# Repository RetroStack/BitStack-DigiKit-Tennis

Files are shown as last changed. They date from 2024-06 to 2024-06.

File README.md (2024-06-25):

# DigiKit Tennis Replica

While watching my regular YouTube channels, I saw a digital electronics kit from the 70s called Tennis from the company DigiKit, [shown on the Tech Time Traveller](https://www.youtube.com/watch?v=UqEwdttDtZE&t=2260s). This is a neat little board with a fun game that looks useful for beginners to learn digital electronics. The provided schematic had a lot of bugs and was very incorrect. 

I spent some time reverse engineering it from screenshots of the YouTube video, and the result is this board.

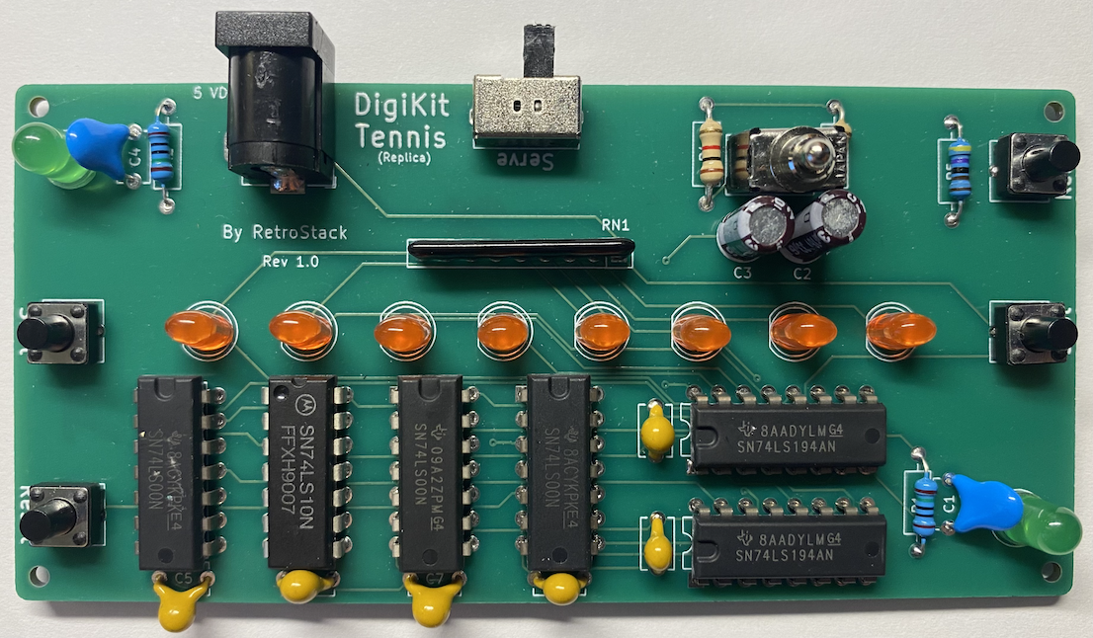
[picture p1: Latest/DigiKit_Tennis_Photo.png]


## Latest Files

In the "Latest" folder, you'll find the most up-to-date design files, including:

- Gerber files suitable for popular online PCB manufacturers like [PCBWay](/Latest/DigiKit_Tennis_Gerber_PCBWay.zip) and [JLCPCB](/Latest/DigiKit_Tennis_Gerber_JLCPCB.zip). Most manufacturers should be fine with either.
- A Bill of Materials (BOM) in both [CSV](/Latest/DigiKit_Tennis_BOM.csv) and [PDF](/Latest/DigiKit_Tennis_BOM.pdf) formats.
- The [full schematics](/Latest/DigiKit_Tennis_Schematics.pdf) of the board.

## How to Play

This is a simple game of Pong where the lights in the center of the board are used to indicate the path of the "ball." The goal of the game is to hit the ball back to the other player. When the player on the receiving end misses the ball, a point is given to the one sending it. The counting needs to be done independently and is not done on the board.

### How to set it up?

1. The first option to set is the toggle switch, which defines the speed of the ball. It should remain the same for the duration of the game.
2. Next, select who should serve the first ball. Switch the "Serve" slide switch to the side of the player who should serve. Then, press any "Reset" button. If the green light is not on the correct side of the person serving, switch it by pressing the "Shot" button from the other side. This will toggle the light.

### Play

When everything is set up, the serving player should press the "Shot" button on their side. (A red light and a green light should be lit on the same side!) As soon as "Shot" is pressed, a simulated "ball" is animated across the lights in the center. When the last light is reached, the other player needs to return it by pressing "Shot" in time on their side.

## Implementation

The replica has been implemented using KiCAD 8. The KiCAD project files are included in this repository.

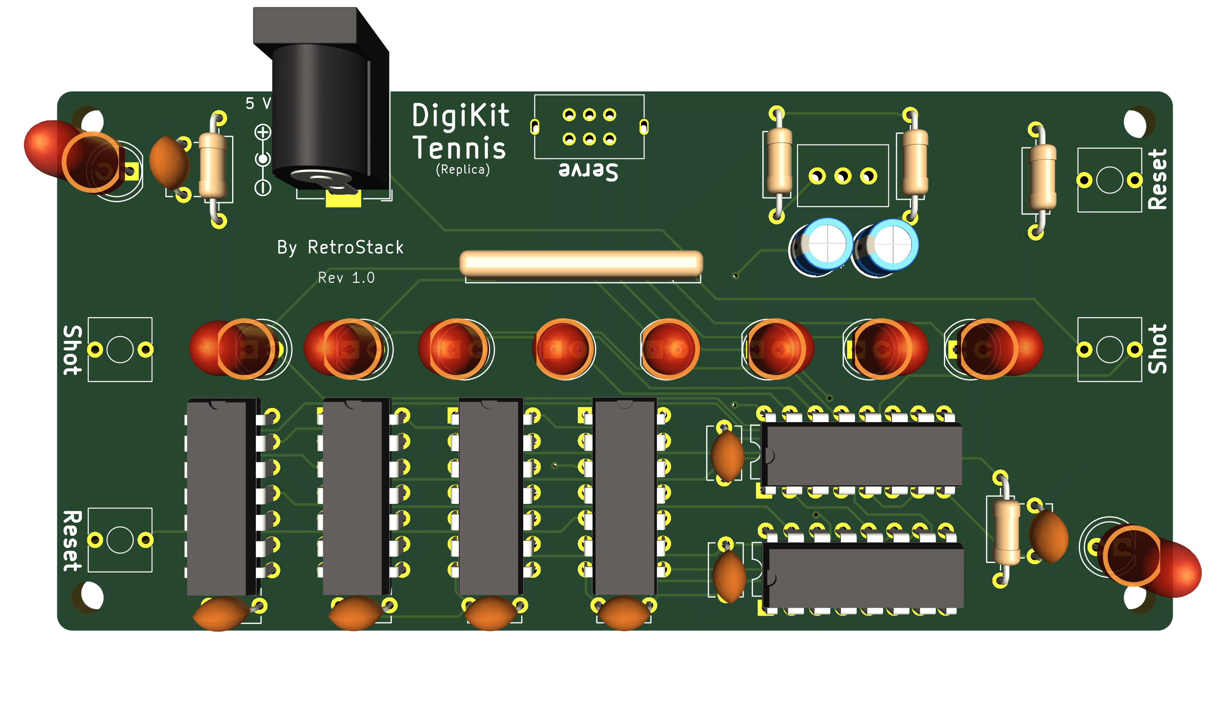
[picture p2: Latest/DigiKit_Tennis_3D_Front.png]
Replica Front

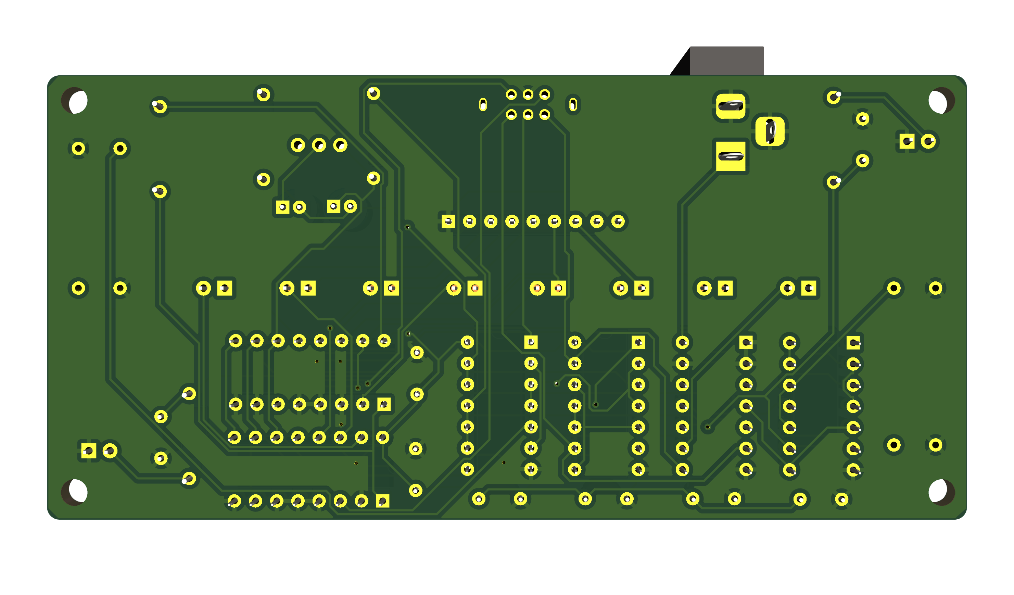
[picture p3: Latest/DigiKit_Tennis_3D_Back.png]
Replica Back


## Bill of Materials (BOM)

Below is a list of materials needed to assemble the PCB.

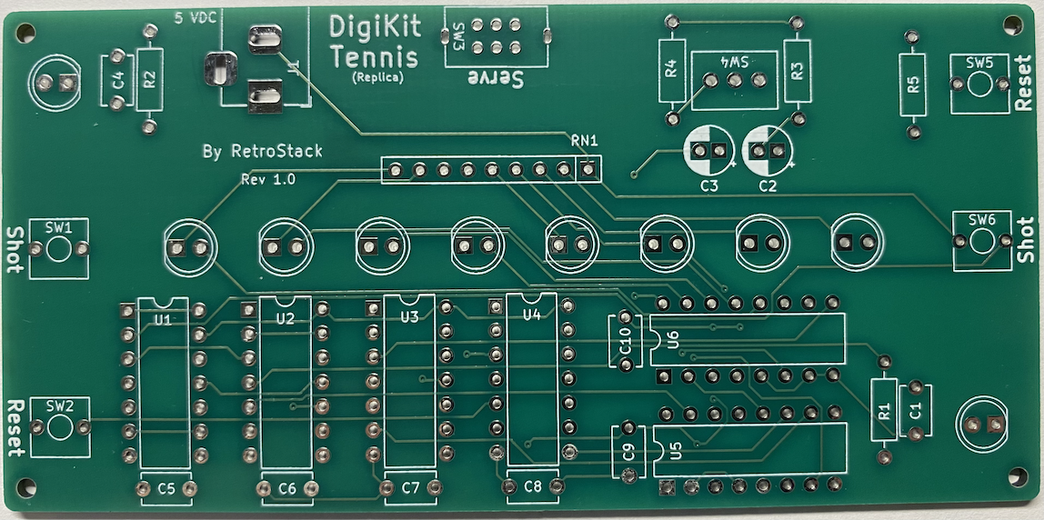
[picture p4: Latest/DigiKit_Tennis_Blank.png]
Board


| Reference | Qty | Description | Footprint | Datasheet |
| --- | --- | --- | --- | --- |
| C1,C4 | 2 | 2nF | Capacitor_THT:C_Disc_D5.1mm_W3.2mm_P5.00mm | |
| C2,C3 | 2 | 33uF | Capacitor_THT:CP_Radial_D5.0mm_P2.00mm | |
| C5,C6,C7,C8,C9,C10 | 6 | 0.1uF | Capacitor_THT:C_Disc_D5.1mm_W3.2mm_P5.00mm | |
| D1,D10 | 2 | Green | LED_THT:LED_D5.0mm | |
| D2,D3,D4,D5,D6,D7,D8,D9 | 8 | Red | LED_THT:LED_D5.0mm | |
| J1 | 1 | Barrel_Jack_Switch | Connector_BarrelJack:BarrelJack_Horizontal | |
| R1,R2,RN1 | 2 | 150 | Resistor_THT:R_Axial_DIN0207_L6.3mm_D2.5mm_P10.16mm_Horizontal | |
| RN1 | 1 | 150 | 8 Resistors; 9 pins | |
| R3,R4 | 2 | 1k | Resistor_THT:R_Axial_DIN0207_L6.3mm_D2.5mm_P10.16mm_Horizontal | |
| R5 | 1 | 4.7k | Resistor_THT:R_Axial_DIN0207_L6.3mm_D2.5mm_P10.16mm_Horizontal | |
| SW1 | 1 | Player A | RetroStackLibrary:SW_SPST_Push | |
| SW2 | 1 | Reset A | RetroStackLibrary:SW_SPST_Push | |
| SW3 | 1 | Serve | RetroStackLibrary:SW_DPDT_Slide_RightAngle | |
| SW4 | 1 | Speed | RetroStackLibrary:SW_SPDT_Toggle | |
| SW5 | 1 | Reset B | RetroStackLibrary:SW_SPST_Push | |
| SW6 | 1 | Player B | RetroStackLibrary:SW_SPST_Push | |
| U1,U3,U4 | 3 | 74LS00 | Package_DIP:DIP-14_W7.62mm | http://www.ti.com/lit/gpn/sn74ls00  |
| U2 | 1 | 74LS10 | Package_DIP:DIP-14_W7.62mm | http://www.ti.com/lit/gpn/sn74LS10  |
| U5,U6 | 2 | 74LS194 | Package_DIP:DIP-16_W7.62mm | http://www.ti.com/lit/gpn/sn74LS194 |

## RetroStack Libraries

To work with this KiCAD project, you'll need the RetroStack libraries for KiCAD. Please [follow this link](https://www.github.com/RetroStack/KiCAD-Libraries) to access and install these libraries.

## Support this Project

RetroStack is passionate about exploring and preserving the legacy of older computer systems. BitStack is a sub-project of RetroStack, focusing on education in digital electronics. My work involves creating detailed documentation and videos to share the knowledge. I am also dedicated to reviving these classic systems by reimplementing them and offering replacement parts at no cost. If you're keen on supporting this unique project, I invite you to visit my [Patreon page](https://www.patreon.com/RetroStack). Your support would be immensely valuable and greatly appreciated!

## License

This project is licensed under the MIT License - see the [LICENSE](LICENSE) file for details.

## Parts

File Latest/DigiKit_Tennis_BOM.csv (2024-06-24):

Reference | Value | Datasheet | Footprint | Qty
C1,C4 | 2nF | ~ | Capacitor_THT:C_Disc_D5.1mm_W3.2mm_P5.00mm | 2
C2,C3 | 33uF | ~ | Capacitor_THT:CP_Radial_D5.0mm_P2.00mm | 2
C5,C6,C7,C8,C9,C10 | 0.1uF | ~ | Capacitor_THT:C_Disc_D5.1mm_W3.2mm_P5.00mm | 6
D1,D10 | Green | ~ | LED_THT:LED_D5.0mm | 2
D2,D3,D4,D5,D6,D7,D8,D9 | Red | ~ | LED_THT:LED_D5.0mm | 8
J1 | Barrel_Jack_Switch | ~ | Connector_BarrelJack:BarrelJack_Horizontal | 1
R1,R2 | 150 | ~ | Resistor_THT:R_Axial_DIN0207_L6.3mm_D2.5mm_P10.16mm_Horizontal | 2
RN1 | 150 | ~ | 8 Resistors; 9 pin | 1
R3,R4 | 1k | ~ | Resistor_THT:R_Axial_DIN0207_L6.3mm_D2.5mm_P10.16mm_Horizontal | 2
R5 | 4.7k | ~ | Resistor_THT:R_Axial_DIN0207_L6.3mm_D2.5mm_P10.16mm_Horizontal | 1
SW1 | Player A | ~ | RetroStackLibrary:SW_SPST_Push | 1
SW2 | Reset A | ~ | RetroStackLibrary:SW_SPST_Push | 1
SW3 | Serve | ~ | RetroStackLibrary:SW_DPDT_Slide_RightAngle | 1
SW4 | Speed | ~ | RetroStackLibrary:SW_SPDT_Toggle | 1
SW5 | Reset B | ~ | RetroStackLibrary:SW_SPST_Push | 1
SW6 | Player B | ~ | RetroStackLibrary:SW_SPST_Push | 1
U1,U3,U4 | 74LS00 | http://www.ti.com/lit/gpn/sn74ls00 | Package_DIP:DIP-14_W7.62mm | 3
U2 | 74LS10 | http://www.ti.com/lit/gpn/sn74LS10 | Package_DIP:DIP-14_W7.62mm | 1
U5,U6 | 74LS194 | http://www.ti.com/lit/gpn/sn74LS194 | Package_DIP:DIP-16_W7.62mm | 2

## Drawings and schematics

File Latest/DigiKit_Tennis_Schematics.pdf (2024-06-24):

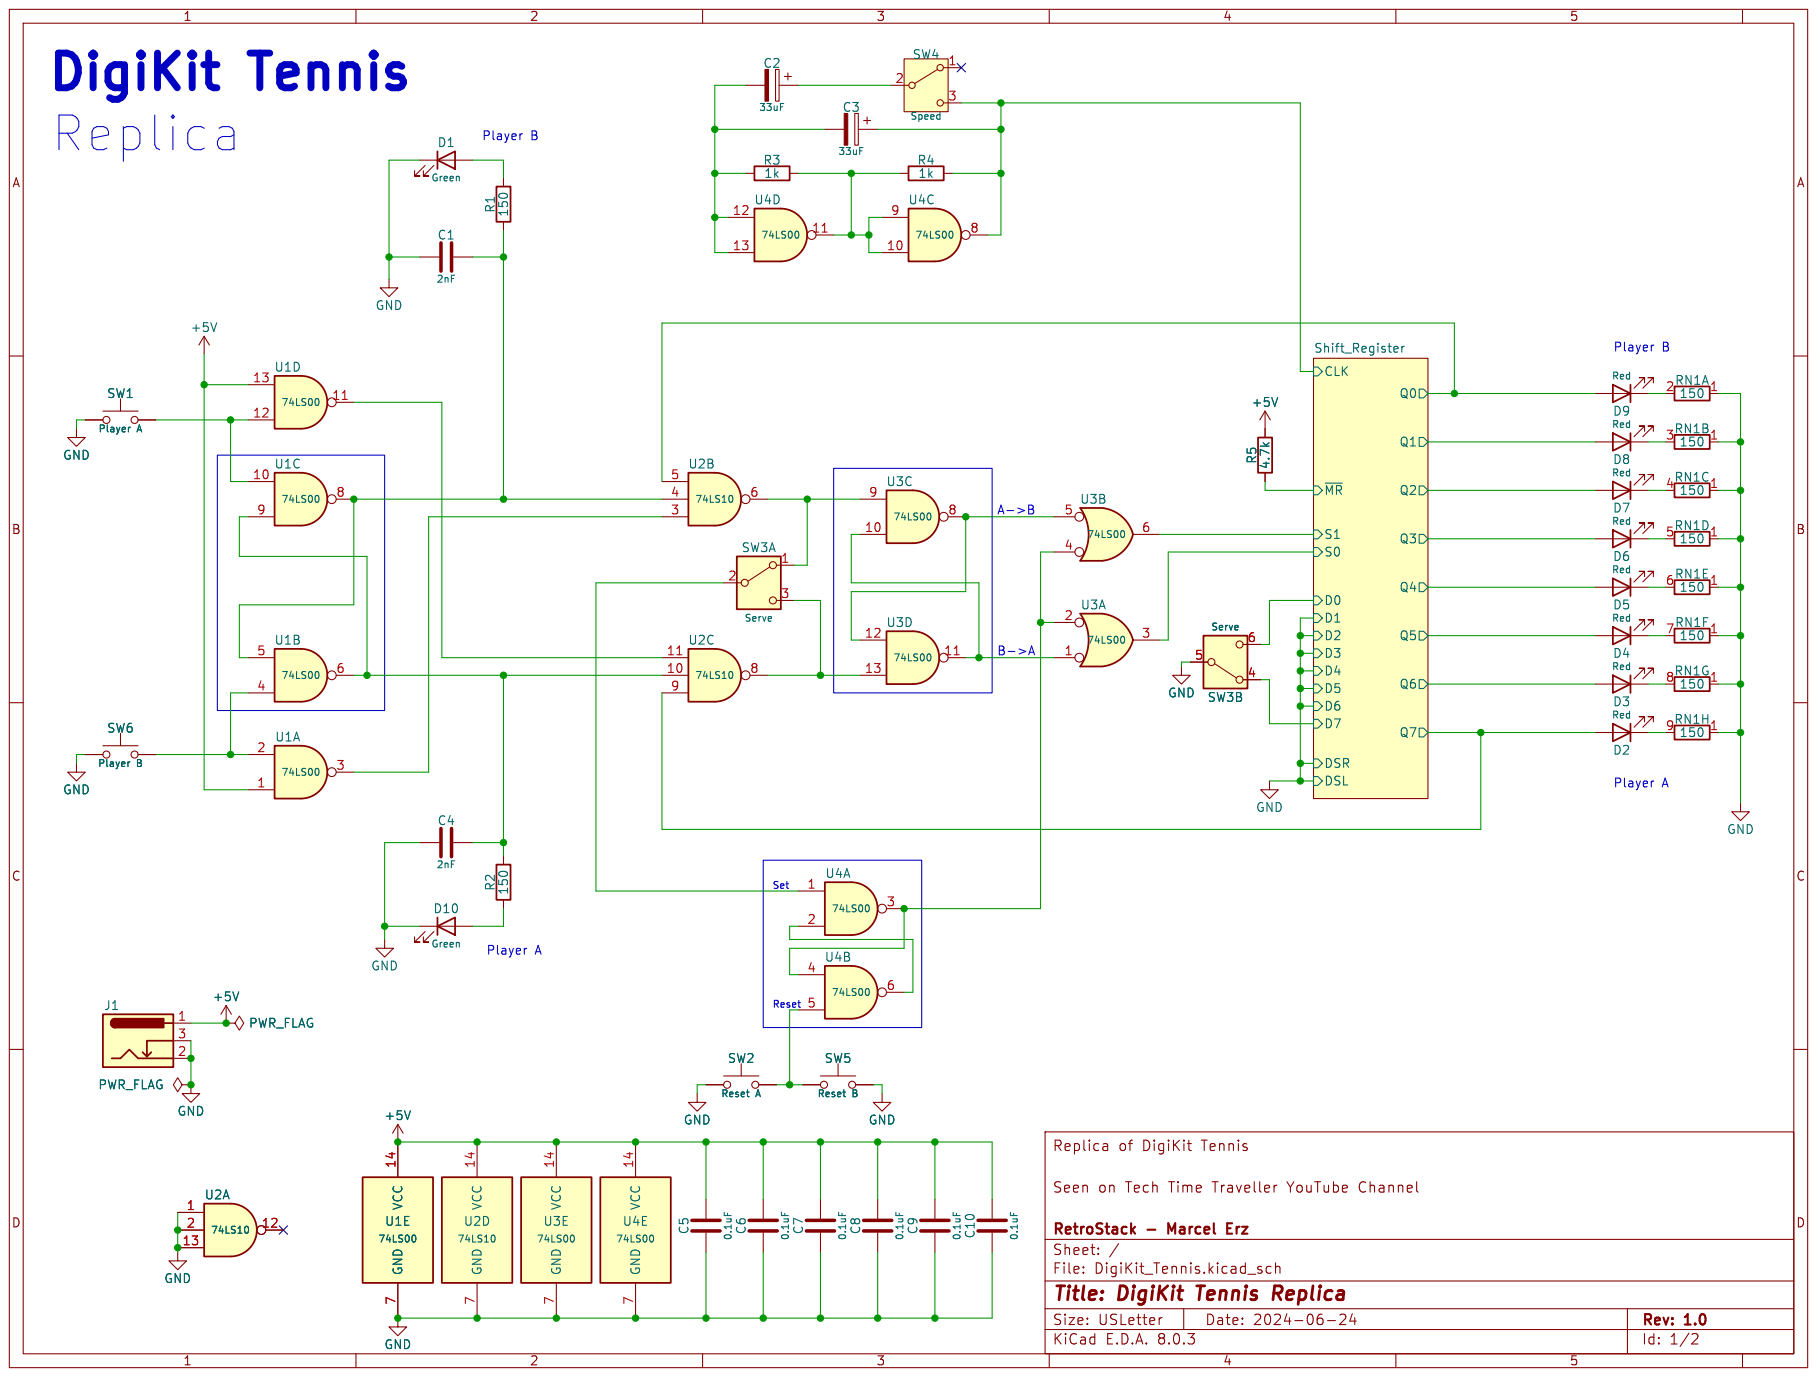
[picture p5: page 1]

150 D6 Red D5 Red D7 Red D8 Red D9 Red VCC 14 GND 7 U3E

Id: 1/2 Title: DigiKit Tennis Replica

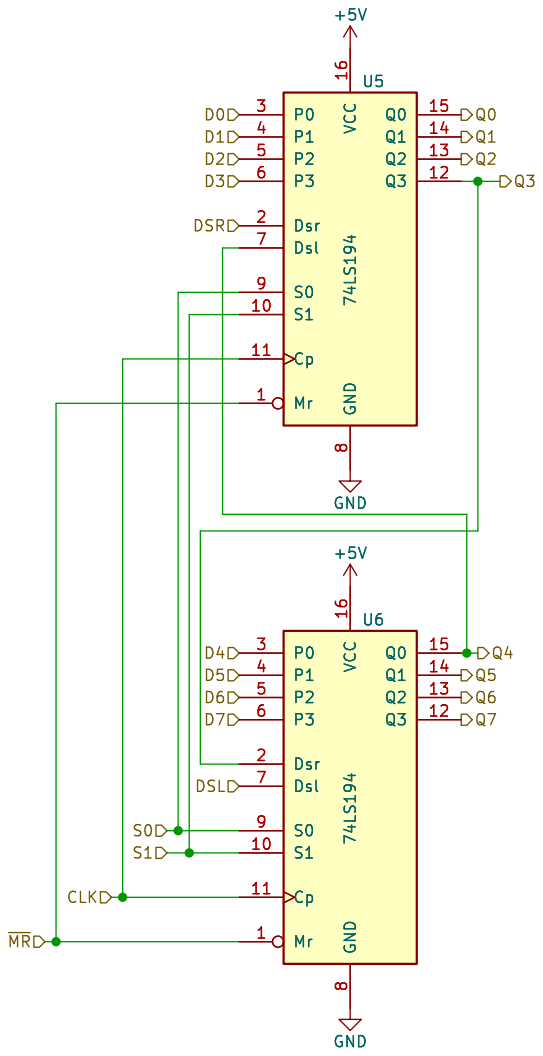
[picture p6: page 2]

Id: 2/2 Title: DigiKit Tennis Replica

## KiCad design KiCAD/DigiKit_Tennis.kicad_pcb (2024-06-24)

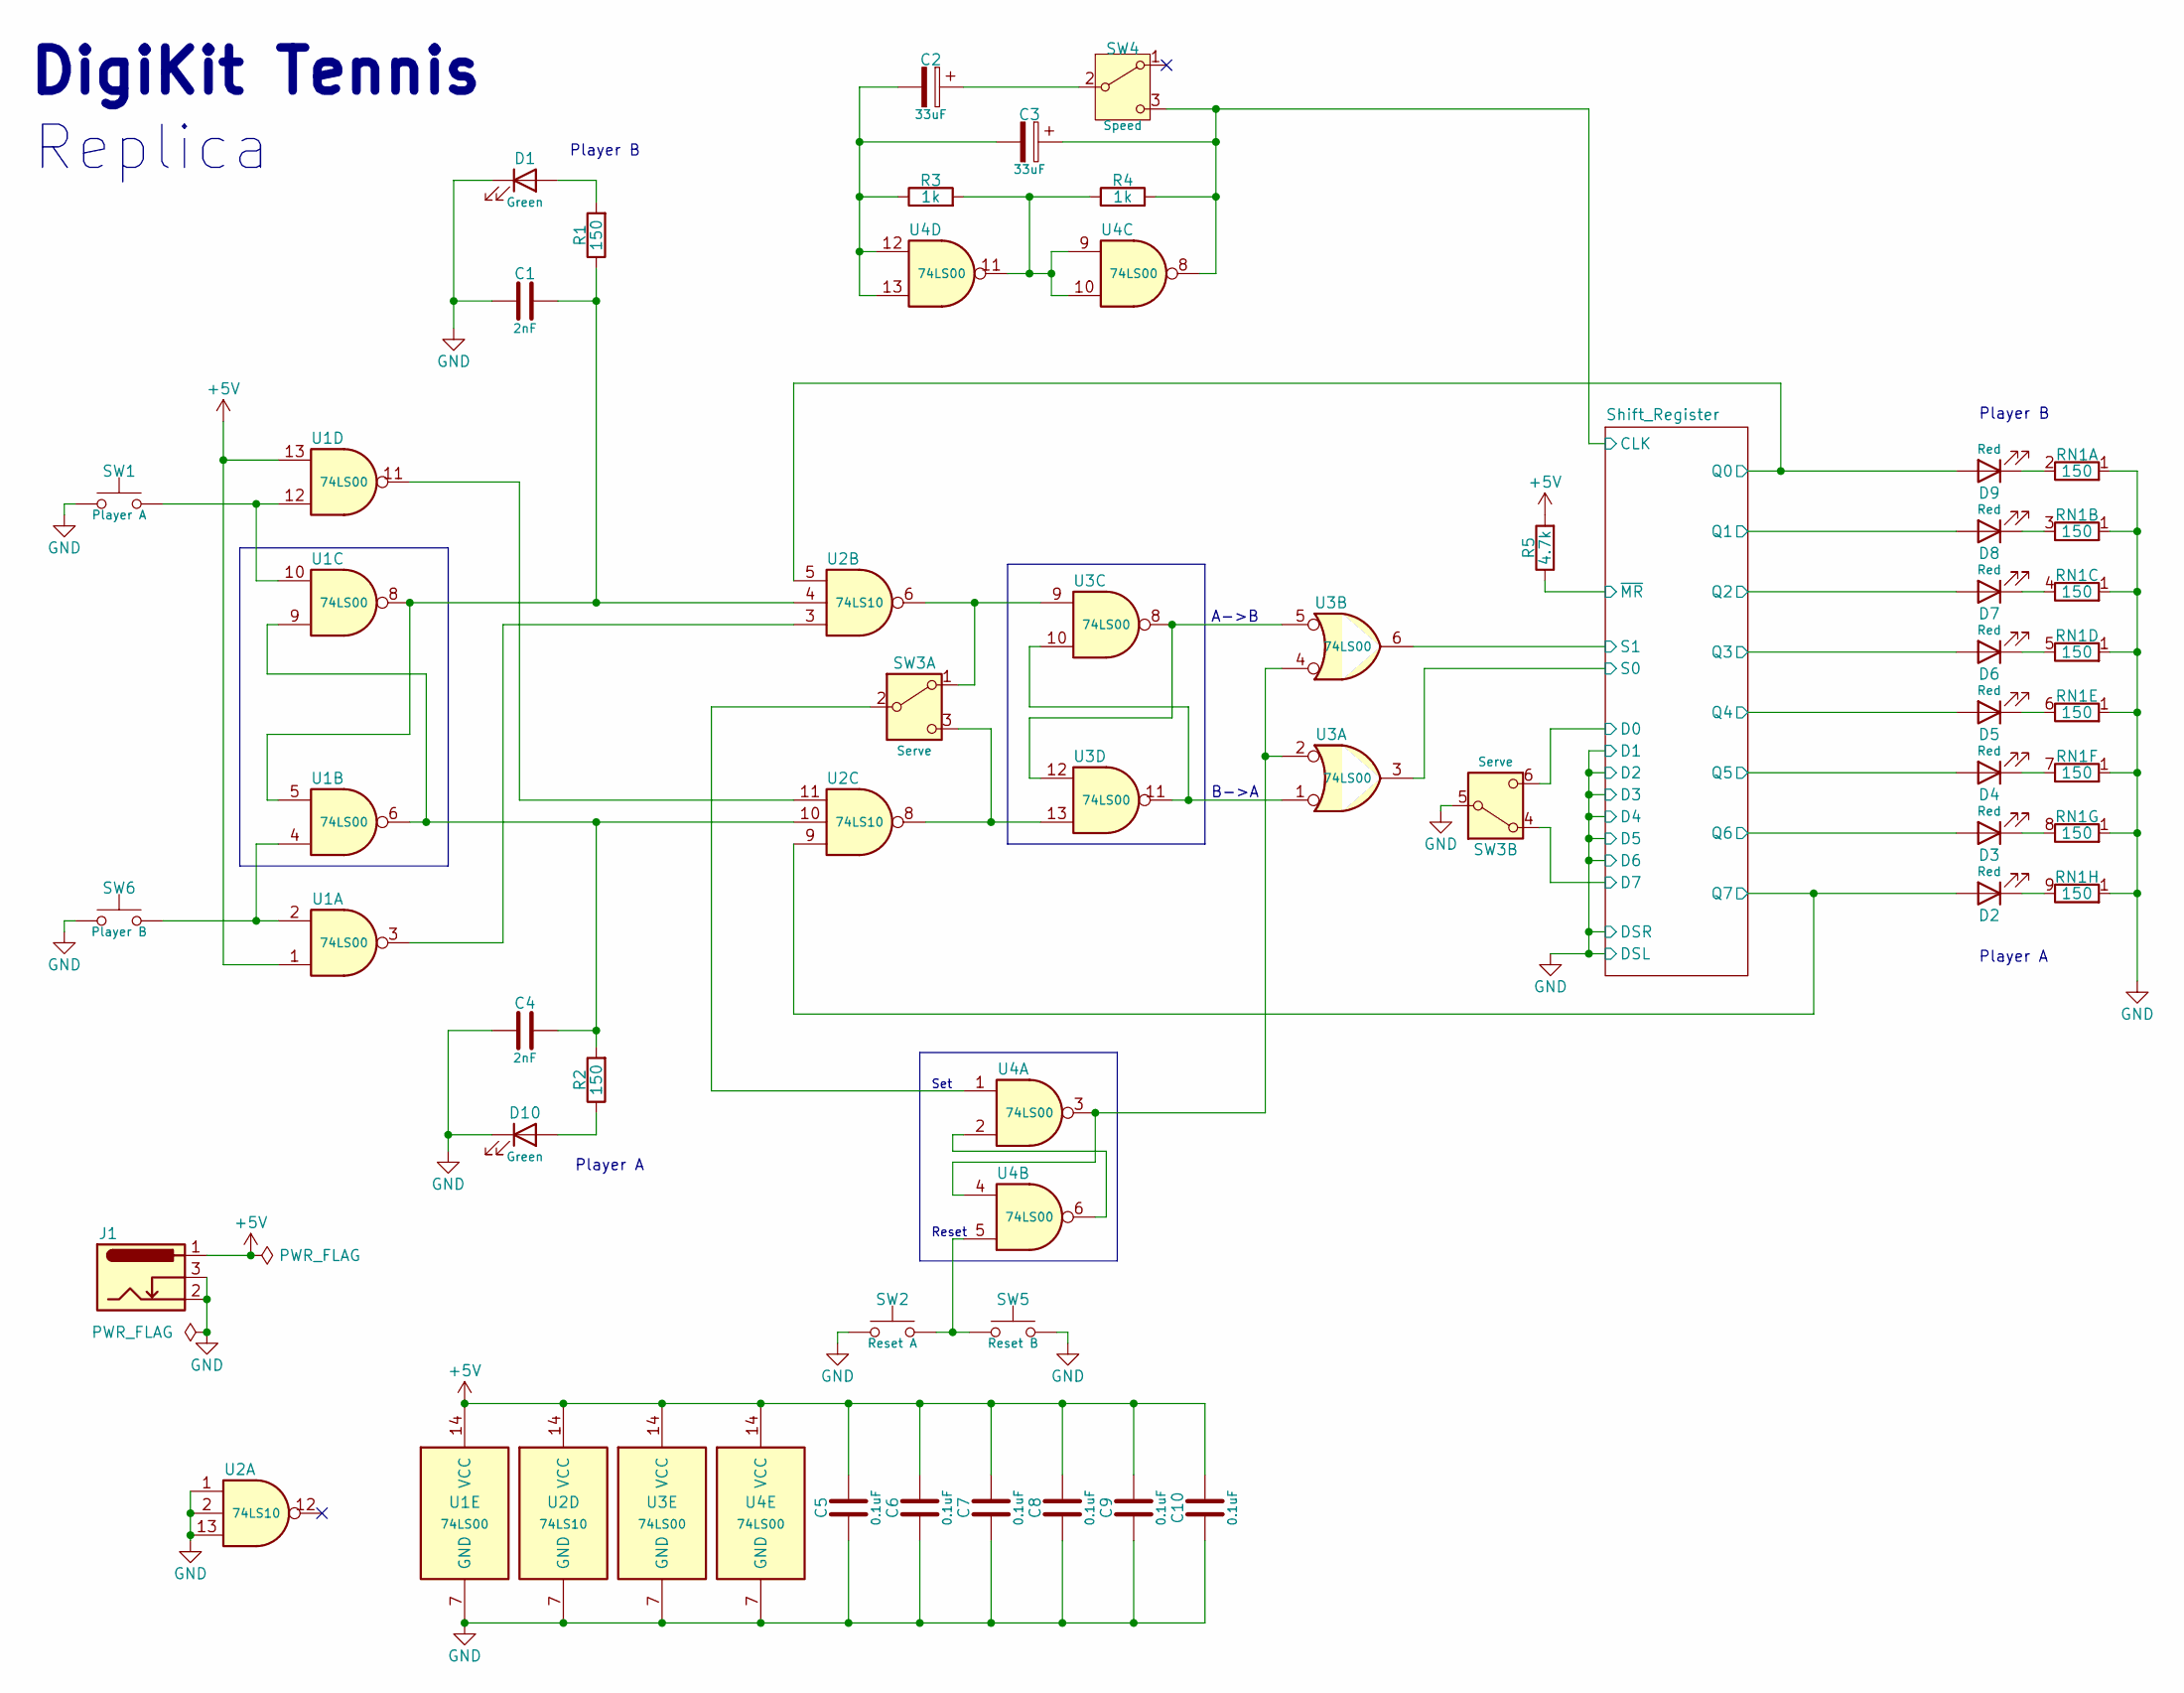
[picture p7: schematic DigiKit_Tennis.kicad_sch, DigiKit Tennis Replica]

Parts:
C1, C4: 2nF; C_Disc_D5.1mm_W3.2mm_P5.00mm
C2, C3: 33uF; CP_Radial_D5.0mm_P2.00mm
C5, C6, C7, C8, C9, C10: 0.1uF; C_Disc_D5.1mm_W3.2mm_P5.00mm
D1, D10: Green; LED_D5.0mm
D2, D3, D4, D5, D6, D7, D8, D9: Red; LED_D5.0mm
J1: Barrel_Jack_Switch; BarrelJack_Horizontal
R1, R2: 150; R_Axial_DIN0207_L6.3mm_D2.5mm_P10.16mm_Horizontal
R3, R4: 1k; R_Axial_DIN0207_L6.3mm_D2.5mm_P10.16mm_Horizontal
R5: 4.7k; R_Axial_DIN0207_L6.3mm_D2.5mm_P10.16mm_Horizontal
RN1: 150; R_Array_SIP9
SW1: Player A; SW_SPST_Push
SW2: Reset A; SW_SPST_Push
SW3: Serve; SW_DPDT_Slide_RightAngle
SW4: Speed; SW_SPDT_Toggle
SW5: Reset B; SW_SPST_Push
SW6: Player B; SW_SPST_Push
U1, U3, U4: 74LS00; DIP-14_W7.62mm
U2: 74LS10; DIP-14_W7.62mm

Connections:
+5V: C5.1, C6.1, C7.1, C8.1, C9.1, C10.1, J1.1, R5.2, U1.1, U1.13, U1.14 (VCC), U2.14 (VCC), U3.14 (VCC), U4.14 (VCC); also elsewhere on the board
/Shift_Register/CLK: C3.1, R4.2, SW4.3 (C), U4.8; also elsewhere on the board
/Shift_Register/D0: SW3.6 (C); also elsewhere on the board
/Shift_Register/D7: SW3.4 (A); also elsewhere on the board
/Shift_Register/Q0: D9.2 (A), U2.5; also elsewhere on the board
/Shift_Register/Q1: D8.2 (A); also elsewhere on the board
/Shift_Register/Q2: D7.2 (A); also elsewhere on the board
/Shift_Register/Q3: D6.2 (A); also elsewhere on the board
/Shift_Register/Q4: D5.2 (A); also elsewhere on the board
/Shift_Register/Q5: D4.2 (A); also elsewhere on the board
/Shift_Register/Q6: D3.2 (A); also elsewhere on the board
/Shift_Register/Q7: D2.2 (A), U2.9; also elsewhere on the board
/Shift_Register/S0: U3.3; also elsewhere on the board
/Shift_Register/S1: U3.6; also elsewhere on the board
/Shift_Register/~MR: R5.1; also elsewhere on the board
GND: C1.1, C4.1, C5.2, C6.2, C7.2, C8.2, C9.2, C10.2, D1.1 (K), D10.1 (K), J1.2, J1.3, RN1.1 (R1), SW1.1, SW2.1, SW3.5 (B), SW5.2, SW6.1, U1.7 (GND), U2.1, U2.2, U2.7 (GND), U2.13, U3.7 (GND), U4.7 (GND); also elsewhere on the board
unnamed: C1.2, R1.1, U1.5, U1.8, U2.4
unnamed: C2.2, C3.2, R3.1, U4.12, U4.13
unnamed: C4.2, R2.2, U1.6, U1.9, U2.10
unnamed: D1.2 (A), R1.2
unnamed: D2.1 (K), RN1.9 (R8.2)
unnamed: D3.1 (K), RN1.8 (R7.2)
unnamed: D4.1 (K), RN1.7 (R6.2)
unnamed: D5.1 (K), RN1.6 (R5.2)
unnamed: D6.1 (K), RN1.5 (R4.2)
unnamed: D7.1 (K), RN1.4 (R3.2)
unnamed: D8.1 (K), RN1.3 (R2.2)
unnamed: D9.1 (K), RN1.2 (R1.2)
unnamed: D10.2 (A), R2.1
unnamed: R3.2, R4.1, U4.9, U4.10, U4.11
unnamed: SW1.2, U1.10, U1.12
unnamed: SW2.2, SW5.1, U4.5
unnamed: SW3.1 (A), U2.6, U3.9
unnamed: SW3.2 (B), U4.1
unnamed: SW3.3 (C), U2.8, U3.13
unnamed: C2.1, SW4.2 (B)
unnamed: SW6.2, U1.2, U1.4
unnamed: U1.3, U2.3
unnamed: U1.11, U2.11
unnamed: U3.1, U3.10, U3.11
unnamed: U3.2, U3.4, U4.3, U4.4
unnamed: U3.5, U3.8, U3.12
unnamed: U4.2, U4.6

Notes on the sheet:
Reset
B->A
DigiKit Tennis
Replica
Player B
Player A
Set
A->B

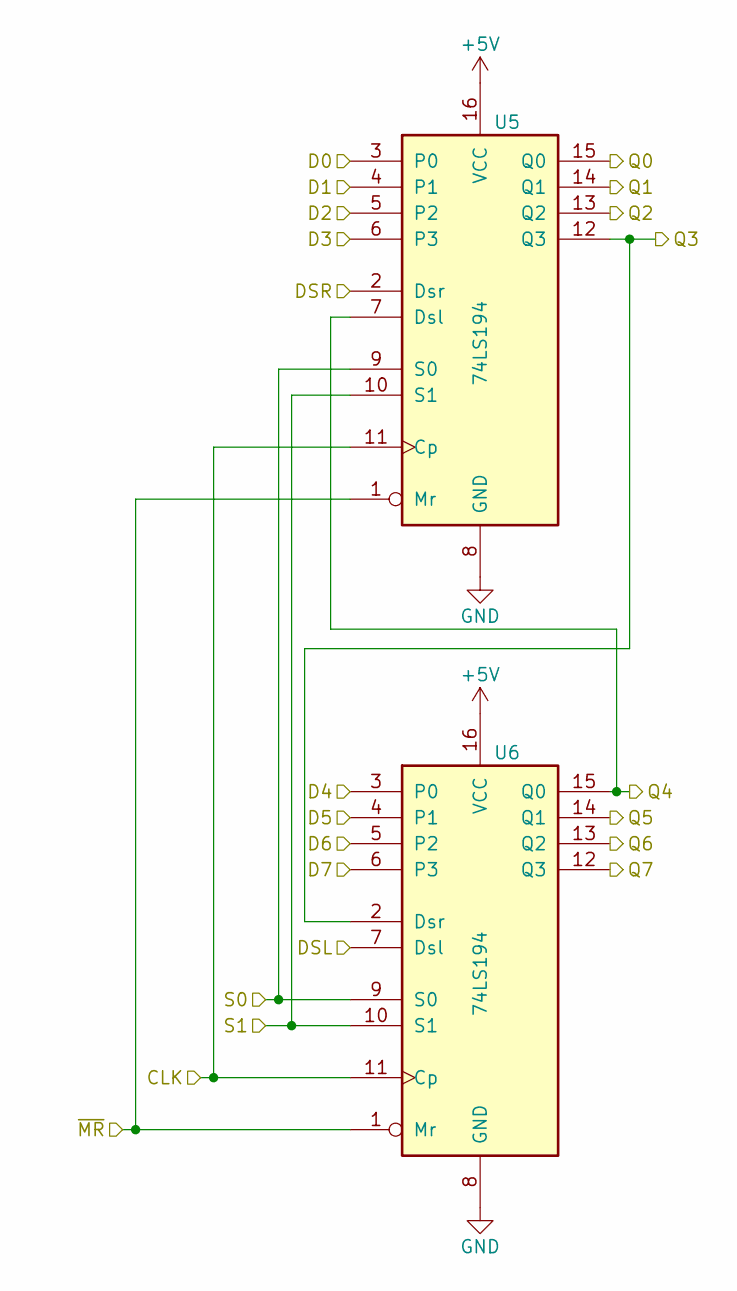
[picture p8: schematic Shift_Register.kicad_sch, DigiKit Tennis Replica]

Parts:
U5, U6: 74LS194; DIP-16_W7.62mm

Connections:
+5V: U5.16 (VCC), U6.16 (VCC); also elsewhere on the board
/Shift_Register/CLK: U5.11 (Cp), U6.11 (Cp); also elsewhere on the board
/Shift_Register/D0: U5.3 (P0); also elsewhere on the board
/Shift_Register/D7: U6.6 (P3); also elsewhere on the board
/Shift_Register/Q0: U5.15 (Q0); also elsewhere on the board
/Shift_Register/Q1: U5.14 (Q1); also elsewhere on the board
/Shift_Register/Q2: U5.13 (Q2); also elsewhere on the board
/Shift_Register/Q3: U5.12 (Q3), U6.2 (Dsr); also elsewhere on the board
/Shift_Register/Q4: U5.7 (Dsl), U6.15 (Q0); also elsewhere on the board
/Shift_Register/Q5: U6.14 (Q1); also elsewhere on the board
/Shift_Register/Q6: U6.13 (Q2); also elsewhere on the board
/Shift_Register/Q7: U6.12 (Q3); also elsewhere on the board
/Shift_Register/S0: U5.9 (S0), U6.9 (S0); also elsewhere on the board
/Shift_Register/S1: U5.10 (S1), U6.10 (S1); also elsewhere on the board
/Shift_Register/~MR: U5.1 (Mr), U6.1 (Mr); also elsewhere on the board
GND: U5.2 (Dsr), U5.4 (P1), U5.5 (P2), U5.6 (P3), U5.8 (GND), U6.3 (P0), U6.4 (P1), U6.5 (P2), U6.7 (Dsl), U6.8 (GND); also elsewhere on the board

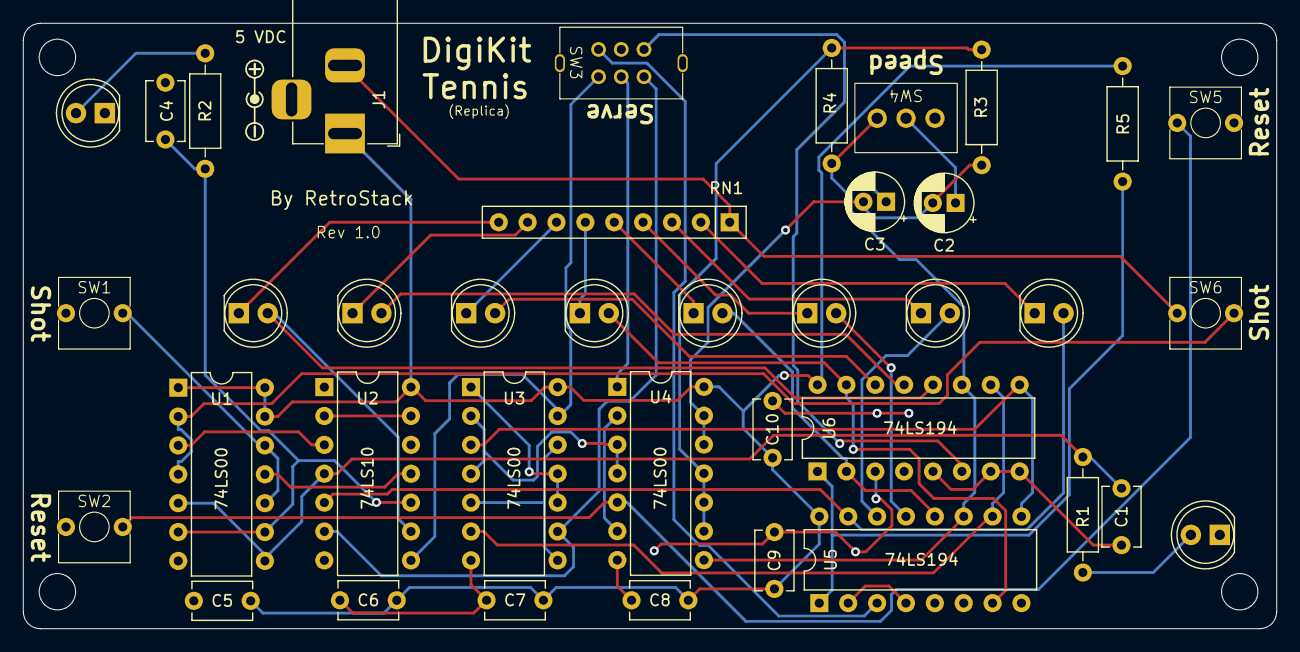
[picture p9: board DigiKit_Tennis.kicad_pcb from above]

Board: 2 copper layers, 110.2 x 53.2 mm, 39 parts (0 on the bottom side), 43 nets.

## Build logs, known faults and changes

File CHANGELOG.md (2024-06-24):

# DigiKit Tennis Replica - Changelog

## 24th June 2024 - Rev 1.0

Completed test. Fully functional.
